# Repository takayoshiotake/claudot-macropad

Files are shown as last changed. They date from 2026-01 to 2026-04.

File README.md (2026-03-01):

# Claudot

> *Each thought ends with a dot.*  
> *The dot is a key.*

[][cc-by-sa]

Claudot is an 12-key macropad.



## Layout

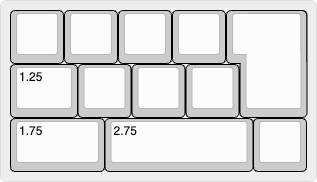
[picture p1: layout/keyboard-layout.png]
Keyboard layout


Named after the Japanese punctuation mark "。", known as **"句点"** (*ku-ten*, pronounced [koo-ten]) — the Japanese *period* or *full stop*.
The word **"句"** (*ku*) refers to either a phrase or a clause — a unit of meaning.

Just as a sentence ends with a dot,
a thought ends with a key.

## Schematic

This project was designed using KiCad.
All design files (schematic and PCB layout) are available in the `kicad/` directory.

Open the `.kicad_pro` file with KiCad to view or edit the project.

PCB schematic
MCU schematic

### FFC Connection

J1 (PCB) and J2 (MCU) are connected using a 0.5 mm pitch, 8-circuit FFC cable (e.g., MOLEX 15166 series compatible).

> [!CAUTION]
> The pin numbering is mirrored between J1 and J2 (1 ↔ 8, 2 ↔ 7, 3 ↔ 6, 4 ↔ 5).

### Key Matrix

This keyboard uses a 3-row by 4-column matrix (12 keys total).
Diodes are configured in the `COL2ROW` direction.

```
Column ──|>|── Switch ── Row
      (A)   (K)
```

### Pin Mapping

| Key Matrix | RP2040 |
|---|---|
| COL0 | GP18 |
| COL1 | GP19 |
| COL2 | GP20 |
| COL3 | GP21 |
| ROW0 | GP**23** |
| ROW1 | GP**22** |
| ROW2 | GP24 |

## Vial

Prebuilt firmware: [claudot_vial.uf2](assets/claudot_vial.uf2).

### Build with Docker

Copy the `vial/claudot` directory to `path/to/your/vial-qmk/keyboards/`.

```bash
SKIP_FLASHING_SUPPORT=1 util/docker_build.sh claudot:vial
```

- <https://get.vial.today/docs/porting-to-vial.html>
- <https://docs.qmk.fm/getting_started_docker>

## License

This work is licensed under a
[Creative Commons Attribution-ShareAlike 4.0 International License][cc-by-sa].

[][cc-by-sa]

[cc-by-sa]: https://creativecommons.org/licenses/by-sa/4.0/
[cc-by-sa-image]: https://licensebuttons.net/l/by-sa/4.0/88x31.png
[cc-by-sa-shield]: https://img.shields.io/badge/license-CC%20BY--SA%204.0-lightgrey.svg

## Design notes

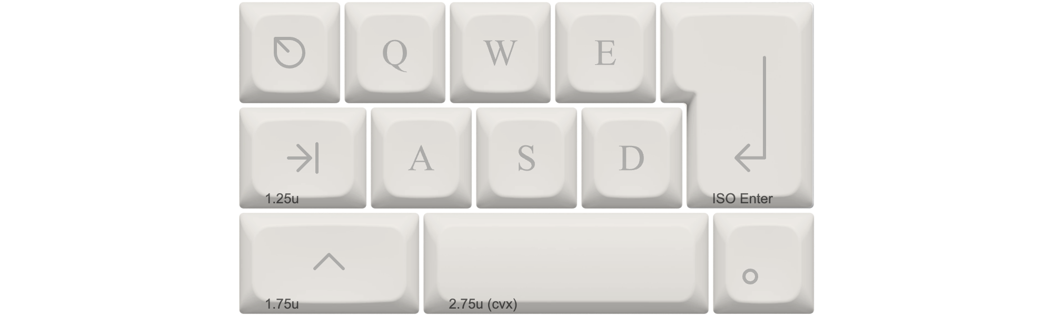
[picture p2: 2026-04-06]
yuzukeycaps/Claudot.png

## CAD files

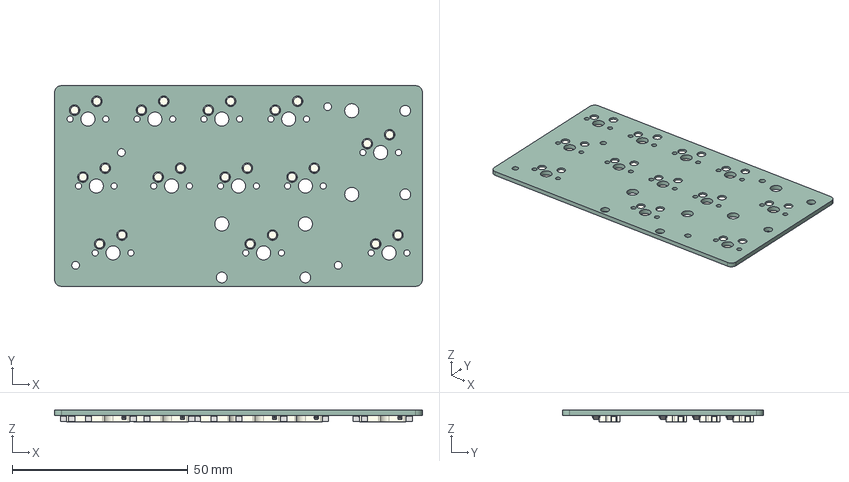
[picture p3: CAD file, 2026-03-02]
assets/Claudot_PCB.step
104.8 x 57.1 x 3.45 mm
D_SOD-323 x 12
Claudot_PCB_PCB

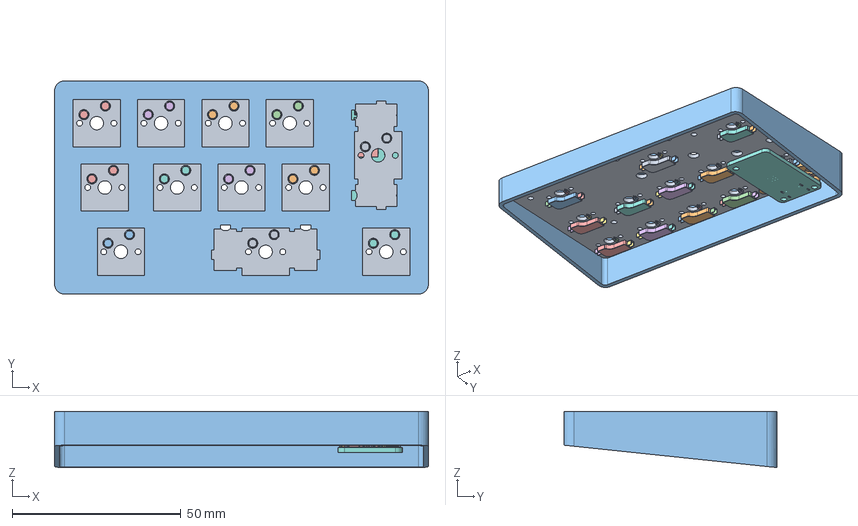
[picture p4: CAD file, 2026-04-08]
housing/claudot.FCStd
110.8 x 63.2 x 16.6 mm
C_0402_1005Metric
C_0402_1005Metric001
R_0402_1005Metric
R_0402_1005Metric001
C_0402_1005Metric002
Winbond_USON-8-1EP_3x2mm_P0.5mm_EP0.2x1.6mm
C_0402_1005Metric003
R_0402_1005Metric002
Fuse_1206_3216Metric
C_0402_1005Metric004
C_0402_1005Metric005
C_0402_1005Metric006
D_SOD-123F
USB_C_Receptacle_GCT_USB4105-xx-A_16P_TopMnt_Horizontal
R_0402_1005Metric003
R_0402_1005Metric004
C_0402_1005Metric007
R_0402_1005Metric005
C_0402_1005Metric008
SOT-23-5
Crystal_SMD_3225-4Pin_3.2x2.5mm
C_0402_1005Metric009
C_0402_1005Metric010
C_0402_1005Metric011
R_0402_1005Metric006
C_0402_1005Metric012
C_0402_1005Metric013
R_0402_1005Metric007
QFN-56-1EP_7x7mm_P0.4mm_EP3.2x3.2mm
C_0402_1005Metric014
C_0402_1005Metric015
Claudot_MCU_PCB
D_SOD-323
D_SOD-324
D_SOD-325
D_SOD-326
D_SOD-327
D_SOD-328
D_SOD-329
D_SOD-330
D_SOD-331
D_SOD-332
D_SOD-333
D_SOD-334
Claudot_PCB_PCB

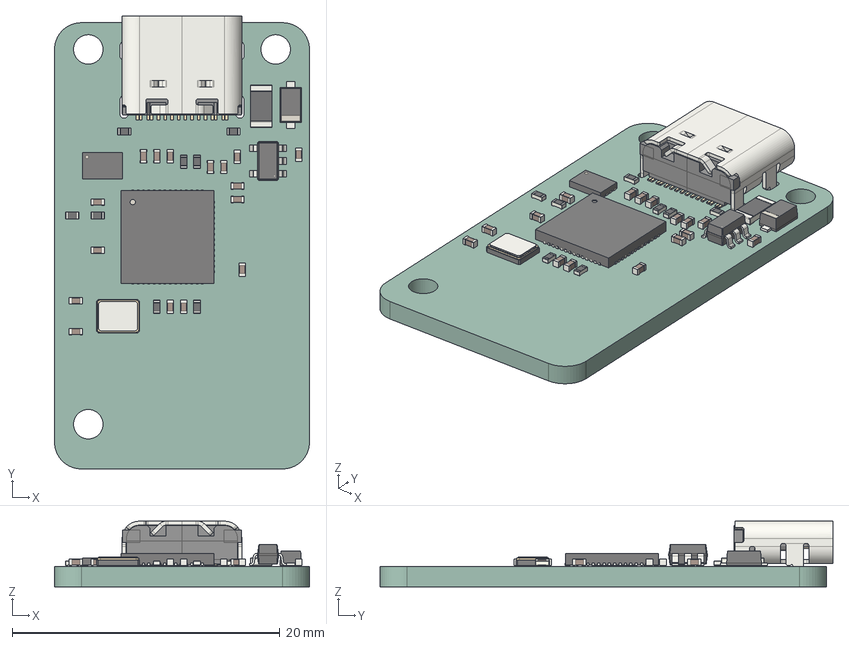
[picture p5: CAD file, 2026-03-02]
assets/Claudot_MCU.step
19.1 x 33.8 x 4.91 mm
C_0402_1005Metric x 16
R_0402_1005Metric x 8
Winbond_USON-8-1EP_3x2mm_P0.5mm_EP0.2x1.6mm
Fuse_1206_3216Metric
D_SOD-123F
USB_C_Receptacle_GCT_USB4105-xx-A_16P_TopMnt_Horizontal
SOT-23-5
Crystal_SMD_3225-4Pin_3.2x2.5mm
QFN-56-1EP_7x7mm_P0.4mm_EP3.2x3.2mm
Claudot_MCU_PCB

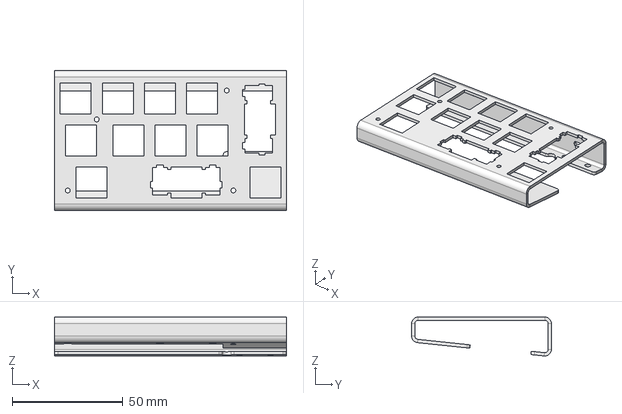
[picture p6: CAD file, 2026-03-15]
housing/claudot-Body037.step
104.8 x 63.1 x 17.6 mm

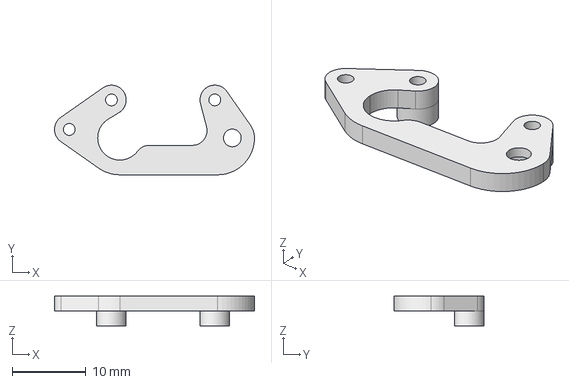
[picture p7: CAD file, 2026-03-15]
housing/claudot-Body036.step
27.1 x 12.1 x 4.00 mm

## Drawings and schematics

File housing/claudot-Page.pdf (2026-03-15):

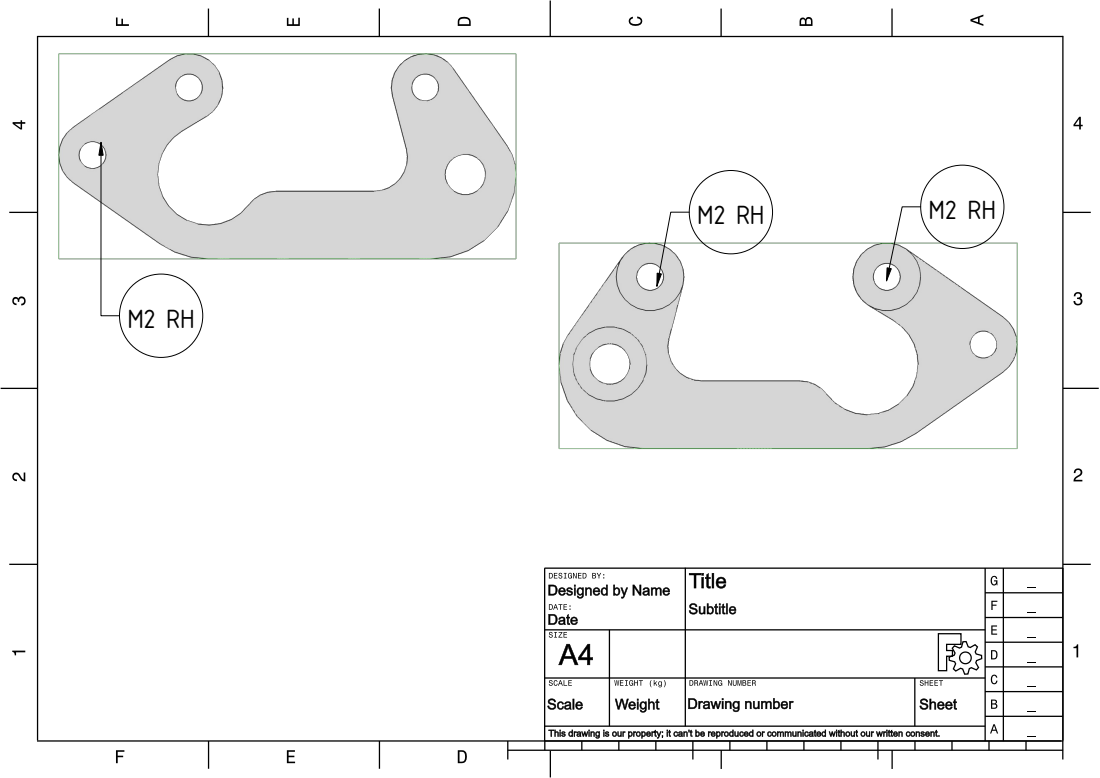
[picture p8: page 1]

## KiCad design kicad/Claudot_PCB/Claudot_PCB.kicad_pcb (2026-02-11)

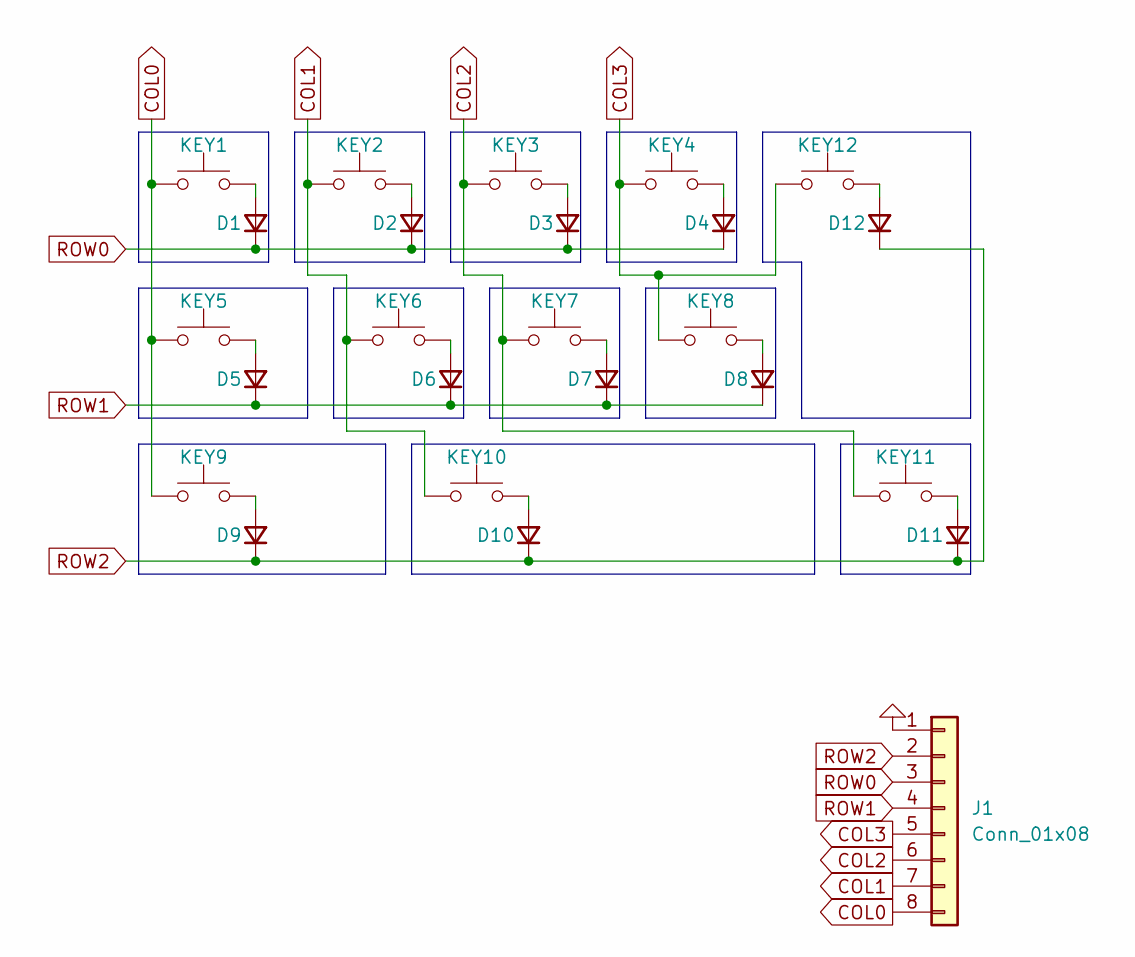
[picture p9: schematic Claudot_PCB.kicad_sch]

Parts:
D1, D2, D3, D4, D5, D6, D7, D8, D9, D10, D11, D12: 1N4148WS; SOD323; LCSC C2128
J1: Conn_01x08; AFC01-S08FCC-00; LCSC C262264
KEY1, KEY2, KEY3, KEY4, KEY5, KEY6, KEY7, KEY8, KEY9, KEY10, KEY11, KEY12: SW_Push; CPG151101S11-16; LCSC C41430893

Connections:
COL0: J1.8, KEY1.1, KEY5.1, KEY9.1
COL1: J1.7, KEY2.1, KEY6.1, KEY10.1
COL2: J1.6, KEY3.1, KEY7.1, KEY11.1
COL3: J1.5, KEY4.1, KEY8.1, KEY12.1
GND: J1.1
unnamed: D1.2 (A), KEY1.2
unnamed: D2.2 (A), KEY2.2
unnamed: D3.2 (A), KEY3.2
unnamed: D4.2 (A), KEY4.2
unnamed: D5.2 (A), KEY5.2
unnamed: D6.2 (A), KEY6.2
unnamed: D7.2 (A), KEY7.2
unnamed: D8.2 (A), KEY8.2
unnamed: D9.2 (A), KEY9.2
unnamed: D10.2 (A), KEY10.2
unnamed: D11.2 (A), KEY11.2
unnamed: D12.2 (A), KEY12.2
ROW0: D1.1 (K), D2.1 (K), D3.1 (K), D4.1 (K), J1.3
ROW1: D5.1 (K), D6.1 (K), D7.1 (K), D8.1 (K), J1.4
ROW2: D9.1 (K), D10.1 (K), D11.1 (K), D12.1 (K), J1.2

Board: 2 copper layers, 25 parts (25 on the bottom side), 19 nets, no tracks yet.

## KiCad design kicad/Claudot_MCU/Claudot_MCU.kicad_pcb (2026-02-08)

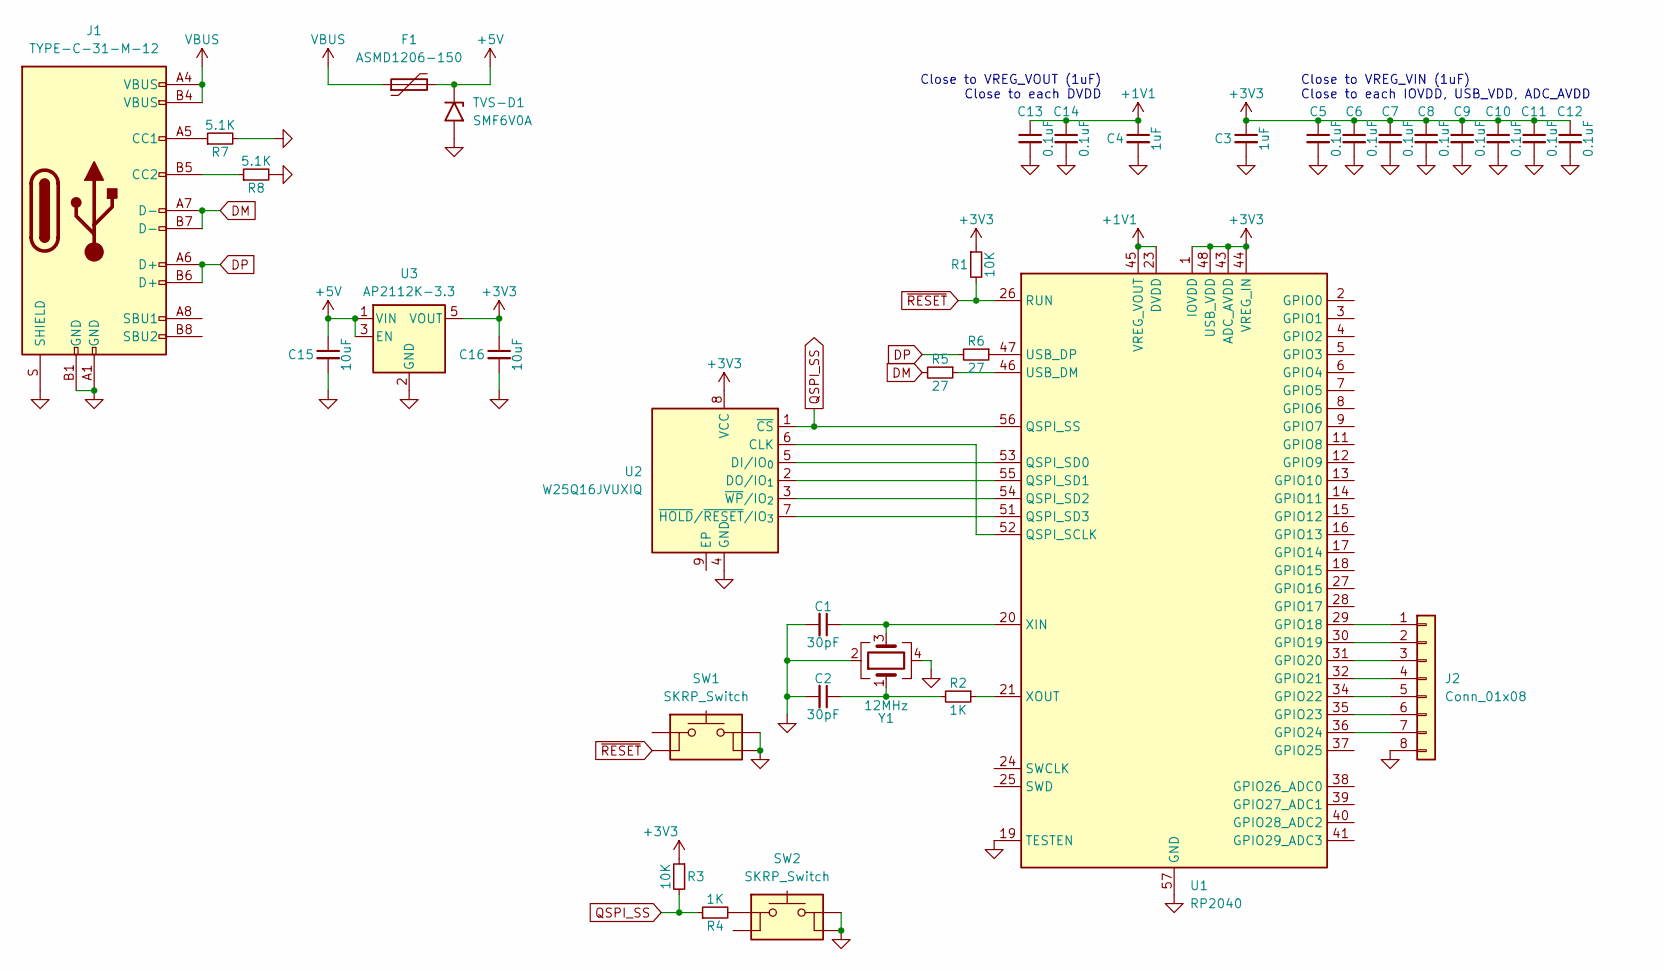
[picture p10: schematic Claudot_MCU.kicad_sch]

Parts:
C1, C2: 30pF; C_0402; LCSC C1570
C3, C4: 1uF; C_0402; LCSC C52923
C5, C6, C7, C8, C9, C10, C11, C12, C13, C14: 0.1uF; C_0402; LCSC C307331
C15, C16: 10uF; C_0402; LCSC C15525
F1: ASMD1206-150; F_1206; LCSC C135342
J1: TYPE-C-31-M-12; LCSC C165948
J2: Conn_01x08; AFC01-S08FCC-00; LCSC C262264
R1, R3: 10K; R_0402; LCSC C25744
R2, R4: 1K; R_0402; LCSC C11702
R5, R6: 27; R_0402; LCSC C352446
R7, R8: 5.1K; R_0402; LCSC C25905
SW1, SW2: SKRP_Switch; LCSC C115360
TVS-D1: SMF6V0A; SMF6.0A; LCSC C178260
U1: RP2040; LCSC C2040
U2: W25Q16JVUXIQ; LCSC C2843335
U3: AP2112K-3.3; SOT25; LCSC C51118
Y1: 12MHz; SMD3225-4P; LCSC C9002

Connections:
+1V1: C4.1, C13.1, C14.1, U1.23 (DVDD), U1.45 (VREG_VOUT), U1.50 (DVDD)
+3V3: C3.1, C5.1, C6.1, C7.1, C8.1, C9.1, C10.1, C11.1, C12.1, C16.1, R1.1, R3.1, U1.1 (IOVDD), U1.10 (IOVDD), U1.22 (IOVDD), U1.33 (IOVDD), U1.42 (IOVDD), U1.43 (ADC_AVDD), U1.44 (VREG_IN), U1.48 (USB_VDD), U1.49 (IOVDD), U2.8 (VCC), U3.5 (VOUT)
+5V: C15.1, F1.2, TVS-D1.1 (A1), U3.1 (VIN), U3.3 (EN)
DM: J1.A7 (D-), J1.B7 (D-), R5.2
DP: J1.A6 (D+), J1.B6 (D+), R6.2
GND: C1.2, C2.2, C3.2, C4.2, C5.2, C6.2, C7.2, C8.2, C9.2, C10.2, C11.2, C12.2, C13.2, C14.2, C15.2, C16.2, J1.A1 (GND), J1.B1 (GND), J1.S (SHIELD), J2.8, R7.2, R8.2, SW1.3, SW1.4, SW2.3, SW2.4, TVS-D1.2 (A2), U1.19 (TESTEN), U1.57 (GND), U2.4 (GND), U3.2 (GND), Y1.2, Y1.4
unnamed: C2.1, R2.2, Y1.1
unnamed: J1.A5 (CC1), R7.1
unnamed: J1.B5 (CC2), R8.1
unnamed: J2.1, U1.29 (GPIO18)
unnamed: J2.2, U1.30 (GPIO19)
unnamed: J2.3, U1.31 (GPIO20)
unnamed: J2.4, U1.32 (GPIO21)
unnamed: J2.5, U1.34 (GPIO22)
unnamed: J2.6, U1.35 (GPIO23)
unnamed: J2.7, U1.36 (GPIO24)
unnamed: R4.2, SW2.1
unnamed: U1.52 (QSPI_SCLK), U2.6 (CLK)
unnamed: U1.53 (QSPI_SD0), U2.5 (DI/IO_{0})
unnamed: U1.55 (QSPI_SD1), U2.2 (DO/IO_{1})
unnamed: U1.54 (QSPI_SD2), U2.3 (~WP/IO_{2})
unnamed: U1.51 (QSPI_SD3), U2.7 (~HOLD/~RESET/IO_{3})
unnamed: R5.1, U1.46 (USB_DM)
unnamed: R6.1, U1.47 (USB_DP)
unnamed: C1.1, U1.20 (XIN), Y1.3
unnamed: R2.1, U1.21 (XOUT)
QSPI_SS: R3.2, R4.1, U1.56 (QSPI_SS), U2.1 (~CS)
VBUS: F1.1, J1.A4 (VBUS), J1.B4 (VBUS)
~RESET: R1.2, SW1.2 (r), U1.26 (RUN)

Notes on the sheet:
Close to VREG_VIN (1uF) Close to each IOVDD, USB_VDD, ADC_AVDD
Close to VREG_VOUT (1uF) Close to each DVDD

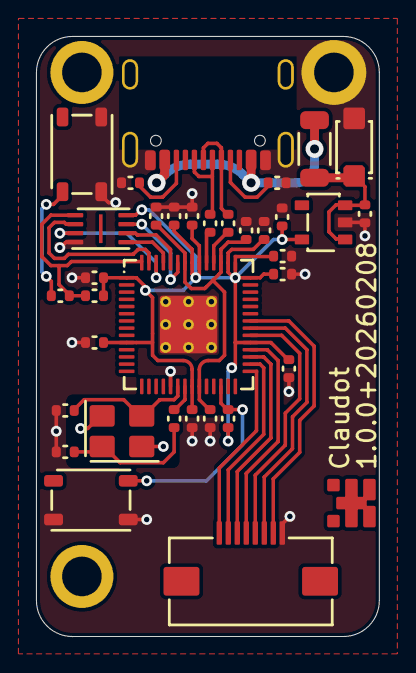
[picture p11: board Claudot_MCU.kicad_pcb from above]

Board: 2 copper layers, 19.0 x 33.3 mm, 34 parts (0 on the bottom side), 29 nets.

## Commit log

2025-08-14 Add initial KiCad project for Claudot
    [Claudot_PCB.kicad_pcb, Claudot_PCB.kicad_sch]
2025-08-14 Add footprint for CPG151101S11-16
2025-08-14 Add footprint for SOD323
2025-08-14 Add footprint for RP2040
2025-08-14 Add footprint for W25Q16JVUXIQ
2025-08-14 Add footprint for SOT25
2025-08-15 Place switches and diodes (no routing)
    [Claudot_PCB.kicad_pcb, Claudot_PCB.kicad_sch]
2025-08-15 Place stabilizers and holes for mounting
    [Claudot_PCB.kicad_pcb]
2025-08-15 Place ICs and rotary encoder
    [Claudot_PCB.kicad_pcb, Claudot_PCB.kicad_sch]
2025-08-15 Update schematic and pcb
    [Claudot_PCB.kicad_pcb, Claudot_PCB.kicad_sch]
2025-08-15 Update courtyard
    [Claudot_PCB.kicad_pcb]
2025-08-16 Reroute traces around U3
    [Claudot_PCB.kicad_pcb]
2025-08-18 Change J1 footprint
    [Claudot_PCB.kicad_pcb, Claudot_PCB.kicad_sch]
2025-08-19 Fix: restore missing hole
    [Claudot_PCB.kicad_pcb]
2025-08-27 Add USB-C connector
    [Claudot_PCB.kicad_pcb, Claudot_PCB.kicad_sch]
2025-09-08 Update routes on pcb
    [Claudot_PCB.kicad_pcb]
2025-09-09 Fix footprint for CPG151101S11-16 and update routes
    [Claudot_PCB.kicad_pcb]
2025-09-12 Update pcb
    [Claudot_PCB.kicad_pcb]
2025-09-13 Move kicad library
2025-09-13 Separate PCB designs into individual KiCad projects
    [Claudot_MCU.kicad_pcb, Claudot_MCU.kicad_sch, Claudot_PCB.kicad_pcb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]
2025-09-13 Cleanup traces
    [Claudot_PCB.kicad_pcb]
2025-09-13 Adjust traces
    [Claudot_PCB.kicad_pcb]
2025-09-14 Update MCU pcb
    [Claudot_MCU.kicad_pcb, Claudot_MCU.kicad_sch]
2026-01-17 concept: remove rotary encoder, return to key-based design
2026-01-17 kicad: replace rotary encoder with key
    [Claudot_PCB.kicad_pcb, Claudot_PCB.kicad_sch]
2026-01-17 kicad: update Claudot_MCU.kicad_pcb
    [Claudot_PCB.kicad_pcb]
2026-02-08 fix: correct row/column net labels
    [Claudot_PCB.kicad_pcb, Claudot_PCB.kicad_sch]
2026-02-08 feat: finalize Claudot_PCB
    [Claudot_PCB.kicad_pcb, Claudot_PCB.kicad_sch]
2026-02-08 feat: finalize Claudot_PCB and Claudot_MCU
    [Claudot_MCU.kicad_pcb, Claudot_MCU.kicad_sch, Claudot_PCB.kicad_pcb]
2026-02-08 chore: complete LCSC part numbers for Claudot_MCU
    [Claudot_MCU.kicad_sch]
2026-02-08 chore: complete LCSC part numbers
    [Claudot_MCU.kicad_pcb, Claudot_PCB.kicad_pcb, Claudot_PCB.kicad_sch]
2026-02-11 refactor: round pcb corners and adjust silkscreen branding placement
    [Claudot_PCB.kicad_pcb]
2026-03-02 Add 3d models
    [Claudot_MCU.step, Claudot_PCB.step]
2026-03-08 Add housing model
    [claudot.FCStd]
2026-03-15 Add 3D parts
    [claudot-Body036.step, claudot.FCStd]
2026-03-15 Add metal sheet housing
    [claudot-Body037.step, claudot.FCStd]

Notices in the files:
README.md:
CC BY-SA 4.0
